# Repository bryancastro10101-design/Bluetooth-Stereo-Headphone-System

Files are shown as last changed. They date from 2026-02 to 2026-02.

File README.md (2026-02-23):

# 🎧 Bluetooth Stereo Headphone System
**EE 445L Embedded System Design Lab — Final Project | The University of Texas at Austin**

A fully functional wireless stereo audio system built from scratch using an ESP32 and TM4C123 microcontroller, featuring real-time DSP, dual TFT displays, and a custom PCB designed in KiCad.

---

## 📌 Project Overview

This project demonstrates end-to-end embedded system design — from hardware architecture and PCB layout to firmware development and digital signal processing. Audio is streamed wirelessly from a PC via Bluetooth (A2DP protocol), decoded by an ESP32, and transmitted over SPI to a TM4C123 microcontroller for processing and playback through dual speakers.

---

## 🏗️ System Architecture

```
[PC / Spotify]
     │
     │  Bluetooth A2DP
     ▼
[ESP32 DevKitC]  ──── SPI ────►  [TM4C123GH6PM]
                                       │
                          ┌────────────┴────────────┐
                          │                         │
                     [TLV5616 DAC]           [TLV5616 DAC]
                          │                         │
                    [MCP34119 OPA]           [MCP34119 OPA]
                          │                         │
                      [Speaker L]             [Speaker R]
                          
         [ST7735R LCD ×2]  ◄── SPI ── TM4C123
         [Volume Buttons ×4]
```

**Communication Protocols:**
- **Bluetooth A2DP** — Wireless audio streaming from PC to ESP32
- **SPI** — ESP32 → TM4C123 audio data transfer; TM4C123 → DACs and LCD screens
- **I2C** — ESP32 ↔ TM4C123 control/status channel

---

## ⚙️ Hardware Components

| Component | Part | Qty | Role |
|---|---|---|---|
| Microcontroller | TM4C123GH6PM | 1 | Main audio processor |
| Wireless MCU | ESP32-DevKitC-V4 | 1 | Bluetooth A2DP receiver |
| TFT Display | ST7735R | 2 | Real-time audio level UI |
| DAC | TLV5616 | 2 | Digital-to-analog conversion |
| Op-Amp | MCP34119P | 2 | Audio amplification |
| Buck Regulator | MPM3610GQV | 2 | 9V → 5V and 9V → 3.3V |
| Voltage Reference | LM4041CILPR | 1 | Stable DAC reference |

---

## 🔋 Power Budget

| Rail | Load Breakdown | Range |
|---|---|---|
| **3.3V** | TM4C123 + 2× ST7735R + ESP32 + regulators + Vref | 231 mA – 321 mA |
| **5V** | 2× MCP34119 + 2× TLV5616 | ~2.32 mA |

Both rails are supplied by MPM3610GQV switching regulators from a 9V source, chosen for their high efficiency and small footprint.

---

## 💻 Firmware Design

### ESP32 — Bluetooth Receiver
Receives audio data over Bluetooth A2DP and streams it to the TM4C123 via SPI as fast as data is available.

```c
// ESP32 pseudocode
int main() {
    while (true) {
        while (SoundDataReady) {
            SPIOut(SoundData);
        }
    }
    return 0;
}
```

### TM4C123 — Audio Processor
Acts as the SPI slave, processes incoming audio data, and distributes it to the two DAC channels and both LCD displays.

**Module structure:**
```
dac.h       → DAC_Init(), DAC_Output(uint16_t data)
slave.h     → Slave_Init(void (*handler)(uint8_t databyte))
speaker.h   → init_Speaker(), play_Sound(int soundData)
lcd.h       → init_LCD(), update_LCD(update_Params params)
```

---

## 🖥️ User Interface

- **2× ST7735R TFT displays** showing real-time audio level visualization that responds dynamically to volume
- **4 buttons** (2 per channel) for:
  - Volume control (up/down)
  - Equalization adjustment

---

## 📐 PCB Design

Designed in **KiCad** targeting **JLCPCB** manufacturing rules.

**Key design decisions:**
- Regulators placed close to the battery connector to minimize long power traces
- Speaker/Amp/DAC subcircuit routed once and mirrored for the stereo channel
- Booster pack headers spaced for TM4C123 LaunchPad compatibility
- Crystal oscillator isolated from high-speed signal traces

---

## 📊 Performance Targets

| Metric | Target |
|---|---|
| Frequency Response | 20 Hz – 20 kHz |
| SNR | ≥ 80 dB |
| Button Response Time | Measured via logic analyzer |
| Bluetooth Range | Up to ~10 m (Class 2) |

---

## 🛠️ Skills Demonstrated

- **Embedded C firmware** on ARM Cortex-M4 (TM4C123)
- **SPI/I2C protocol implementation** (master & slave)
- **Bluetooth A2DP** wireless audio protocol
- **Digital Signal Processing** — real-time audio equalization
- **PCB design** in KiCad (schematic capture, layout, DRC)
- **Analog circuit design** — DAC output stage with op-amp buffering
- **Power electronics** — switching regulator selection and layout
- **Hardware/software co-design** across two MCUs

---

## 📁 Repository Structure

```
├── firmware/
│   ├── esp32/          # Bluetooth A2DP receiver code
│   └── tm4c/           # Audio processor, DAC, LCD, SPI slave
├── hardware/
│   ├── schematic/      # KiCad schematic files
│   ├── pcb/            # KiCad PCB layout files
│   └── datasheets/     # Component datasheets
├── docs/
│   ├── system_diagram.pdf
│   ├── requirements_document.pdf
│   └── power_calculations.txt
└── README.md
```

---

## 🎓 Course Context

**EE 445L — Embedded Systems Design Lab**  
Department of Electrical and Computer Engineering  
The University of Texas at Austin

This course covers real-time embedded system design, hardware/software integration, and PCB prototyping with an emphasis on the full engineering design cycle from requirements through implementation and testing.

---

---

## 📝 Lessons Learned

The board flashed successfully with all components soldered — until the buck converters were added. Once the MPM3610GQV regulators were populated, the board could no longer be programmed via JTAG.

After consulting with other engineers, the team's leading hypothesis is **switching noise crosstalk from the buck converters into the JTAG lines**. The regulators were placed in relative proximity to the JTAG header on a 2-layer PCB, which lacks the dedicated ground and power planes of a 4-layer design. Without those inner planes acting as a Faraday shield and low-impedance return path, the high-frequency switching transients generated by the regulators likely coupled into the JTAG data lines and disrupted the debug interface.

The audio side had its own surprise as well. One of the external ADC converters was producing noticeably poor sound quality that we couldn't tune out. Rather than spin a new board, the team jumped a wire on the back of the PCB to bypass it and route the signal directly into the ESP32's onboard ADC instead — which performed considerably better. It wasn't pretty, but it worked, and the project stayed on schedule. A classic embedded engineering field fix.

**Key takeaways for future designs:**
- Move to a **4-layer stackup** (signal / ground / power / signal) to provide shielding and clean return paths — especially important when mixing switching regulators with sensitive digital interfaces
- Increase the **physical separation** between switching regulators and JTAG/SWD headers, and avoid routing debug lines near regulator switching nodes
- Add **bulk and bypass capacitance** close to the regulator output to suppress switching noise at the source
- Consider adding a **ferrite bead or LC filter** on the power rail feeding the microcontroller to further isolate debug circuitry from regulator noise

---

*Designed and implemented as part of the EE 445L final project. All schematics, firmware, and documentation produced independently.*

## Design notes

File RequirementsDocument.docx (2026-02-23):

## Project Requirements Document: Bluetooth Headphones

1) Overview
  a) Objectives: Why are we doing this project? What is the purpose?

The purpose of this project is to create a fully functional Bluetooth headphone system that demonstrates the integration of wireless audio transmission, user interface features, and sound quality. The objectives include:

Learning about Bluetooth communication protocols and implementation.

Gaining hands-on experience with embedded systems and enclosure design, particularly with the TM4C123GH6PM microcontroller and ESP32-DevKitC. Along with two of the TFT ST7735R LCD screens.

Developing skills in digital signal processing and audio amplification for improved sound output.

  b) Interactions with Existing Systems: Include this if you are connecting to another board
  c) Terminology: Define domain specific terms used in the document.

SPI - SPI is a synchronous serial communication protocol used for short-distance communication, primarily in embedded systems. It enables communication between a master device and one or more slave devices using four primary lines

I2C - I2C is a multi-master, multi-slave, synchronous serial communication protocol used for connecting low-speed devices in embedded systems. It requires only two wires

DAC - A DAC is an electronic component that converts digital signals (usually binary) into analog signals. It takes discrete values and outputs a continuous voltage or current that represents those values, enabling the representation of digital audio, video, and other signals in a form that can be understood by analog devices (like speakers or displays)

Bluetooth - Bluetooth is a wireless technology standard used for short-range communication between devices. It operates in the 2.4 GHz ISM band and allows for data exchange over distances typically up to 100 meters, depending on the Bluetooth class. Common applications include wireless audio streaming, file transfer, and connecting peripheral devices like keyboards, mice, and headphones

Voltage Regulator - A voltage regulator is an electrical device that maintains a constant output voltage level despite variations in input voltage or load conditions. It ensures that electronic components receive a stable voltage supply, which is crucial for their proper operation. Voltage regulators can be linear or switching types, with switching regulators being more efficient for higher power applications

Signal Amplitude - Signal amplitude refers to the maximum extent of a signal's variation from its rest position or average value. In the context of electrical signals, it is often measured in volts and indicates the strength or intensity of the signal. In audio applications, higher amplitude correlates to louder sounds, while in digital signals, amplitude variations can represent different binary states

Periodic Interrupts - Periodic interrupts are signals sent to a processor at regular intervals to prompt it to execute a specific piece of code or routine. This mechanism is commonly used in real-time operating systems (RTOS) and embedded systems to handle tasks that require consistent timing, such as sampling data from sensors or controlling motors. The processor can manage multiple tasks efficiently by prioritizing interrupts based on their timing

Equalization - Equalization (EQ) in Digital Signal Processing (DSP) is a technique used to adjust the balance of specific frequency components in an audio signal. It involves modifying the amplitude of different frequency bands to enhance, reduce, or modify the sound quality and tonal characteristics of audio playback

2) Functional Description
  a) Functionality: What will the system do precisely?
    i) Bluetooth Audio Streaming (connectivity)
    ii) Dual Speaker Output
    iii) User Interface with two LCD screens
    iv) Volume Control
    v) Equalization
  b) Performance: Define the measures and describe how they will be determined.

Audio Quality: Use an oscilloscope to analyze the output waveform of the speakers for frequency response of the audible hearing range: 20 Hz to 20 kHz.

SNR: Measure the output while playing a test tone at a known level and record the noise level to calculate the SNR. The target is to achieve an SNR of at least 80 dB for high-quality audio playback

Response Time: Measurements: Use a logic analyzer to measure the time from pressing a button to the corresponding action (volume change, playback toggle, or equalizer adjustment)

Equalization Effectiveness: Measurements: Evaluate the impact of the equalizer on audio output using frequency response measurements with an oscilloscope.

Determination: Compare audio signals before and after equalization to ensure intended frequency adjustments are achieved. The equalizer should demonstrate noticeable changes in specific frequency bands, allowing users to tailor the audio output to their preferences.

  c) Usability: Describe the interfaces. Be quantitative if possible

TFT Display Interface: A graphical user interface showing changing audio levels depending on the volume of the sound.

Control Buttons: 4 buttons (2 for each speaker) for volume control and equalization functionalities.

Bluetooth Connectivity (I2C)

DAC interface (SPI): Two separate DACs will be connected to process the information from the ESP32 to a corresponding speaker.

3) Deliverables
  a) Roles and Responsibilities: Who will do what? What is the purpose?
  b) Reports: Simply state the reports for Labs 7 8, and 10 will be written
  c) Outcomes: What are the deliverables? How do we know when it is done?
    i) A fully functional prototype of Bluetooth headphones
    ii) Successful pairing and audio playback
    iii) Two working LCDs that provide real-time information
    iv) Comprehensive documentation to include: schematics, code, and a final project report

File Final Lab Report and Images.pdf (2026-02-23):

Lab 10 report ECE445L

Name: __Adam Herring, Michael Mohn, Bryan Castro

EID: __ah58665, msm5332, bc36587

Semester: Fall 2024
Course: ECE445L
A) Objectives:
1. The purpose of this lab was to execute the design and implementation of the custom PCB for a Blutooth headset using both a TM4C123GH6PM and a ESP32. This project integrated two LCDs, two speakers, a 9V battery, 2 buck converters, and the many capacitors for decoupling, resistors with additional connectors for external interfacing. The overall result displayed the song title being played on both LCDs along with varying blue dots on the screen to see voltage changes in the signal being read from the ESP to the TM4C. Additionally, due to issues with the JTAG, we utilized the LaunchPad connectors to program the device. This experience provided valuable insights into the possible complexities of custom PCB design and implementation.
B) Hardware Design Deliverables:
1. N/A
C) Software Design Deliverables:
1. I have pushed my project to GitHub for grading (Yes/No):
2. Deliverable 1: System design diagram of the modules created.

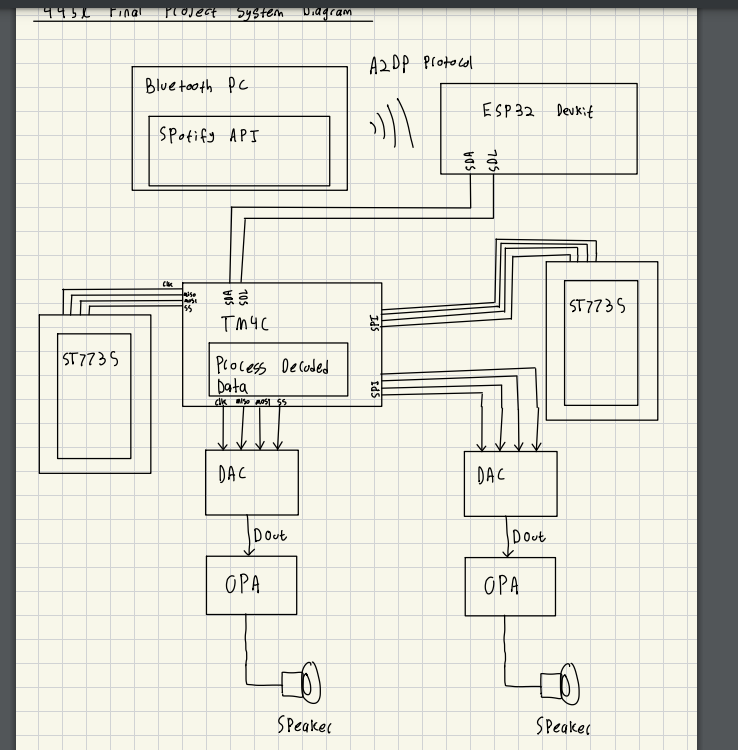
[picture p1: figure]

D) General Deliverables:
1. Deliverable 2: Software Tests
- Verification of the software modules to include Bluetooth connectivity, audio playback through both speakers, reading the ascii characters correctly for the LCDs and overall system control worked except for the external switches because of the hardware issue present with the having to use the launchpad for flashing the program through a TM4C and this launchpad covered the buttons on the PCB.
- Generalized sound quality as a test for data communication was changed from I2C to UART between the ESP32 and TM4C because of the amount of noise present was overbearing in I2C. Both synchronizations were present but there was too much ambiguity to confirm the sound output via I2C because of the noise.

2. Deliverable 3: Hardware Tests
- There were many hardware tests starting from checking if the PCB can flash a program through JTAG. When the PCB was about 90% soldered, aside from the buck converters, we were able to flash the board with no problem. However, after soldering the buck converters, we could not flash any code onto the TM4C of the PCB. After confirming proper voltage values of 3.3V and 1.2V for LDO with the converters soldered and the reset functionality, we deduced the issue of not being able to flash the board to cross talk between the JTAG ports and one of the buck converters that was close to the pins.
- We ensured all 4 test points soldered onto the PCB were functioning properly, with the main focus on ensuring the buck converters change the 9V from the external batter to be changed to 3.3V and 5V. The other two test points were on the out signal of the DACs and before the op-amps needed more testing as we encountered noise in the overall sound output.
3. Deliverable 4: Power consumption

Power consumption for KICAD Lab 7 and 10

Current Drawn from IC (Look at worse case scenario)

(1) TM4C123: ~30–40 mA
(2) ST7735R: ~40 mA
(2) MCP34119P: ~120 µA (per amplifier)
(2) TLV5616: ~1 mA per amp
(1) ESP32 - DEVKITC - V4: ~160–240 mA
(1) MPM3610GQV (From 9V to 5V): ~200 µA
(1) MPM3610GQV (From 9V to 3.3V): ~200 µA
(1) LM4041CILPR: ~60–100 µA

Total Load Currents

For 5V: (~120 µA) +(~120 µA) + (~1 mA) + (~1 mA) + (~160–240 mA) = 160 to 240mA

For 3.3V: (~30–40 mA) + (~40 mA) + (~40 mA) + (~200 µA) + (~200 µA) + (~60–100 µA) = 110.46 mA to 120.5 mA,

4. Deliverable 5 (10pt EC): Characterization of the system
E) Analysis and Discussion Questions:
1. N/A

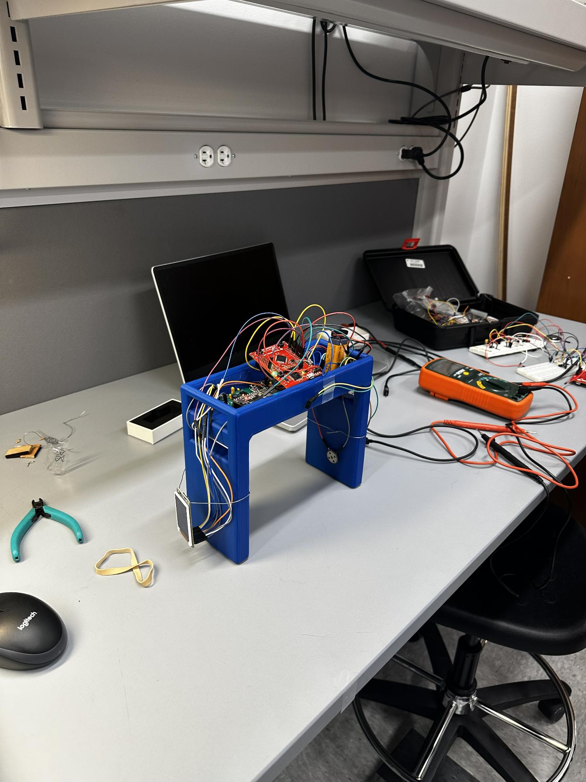
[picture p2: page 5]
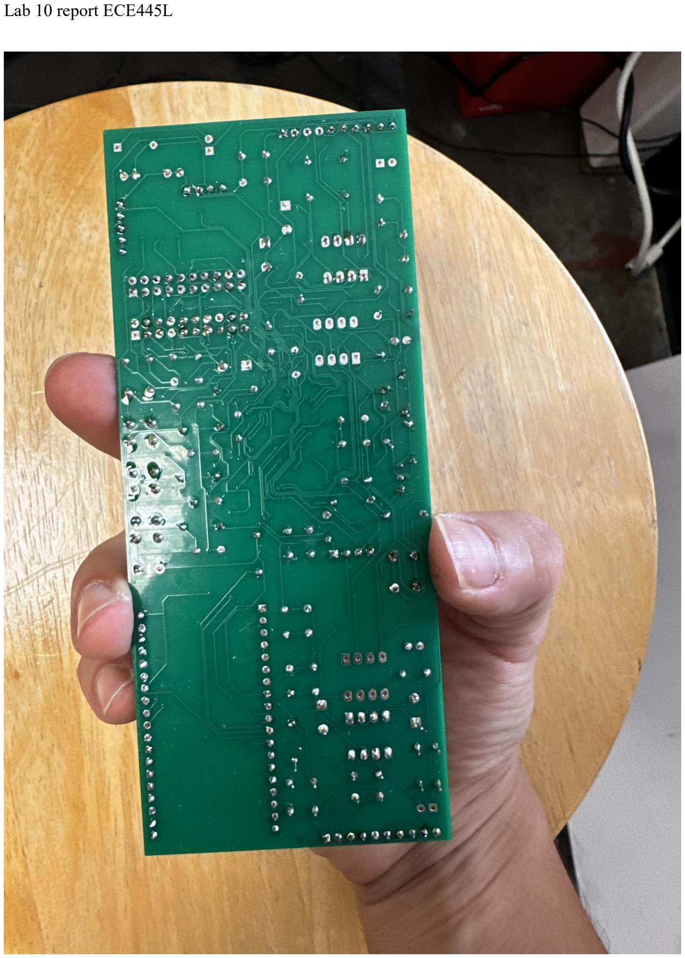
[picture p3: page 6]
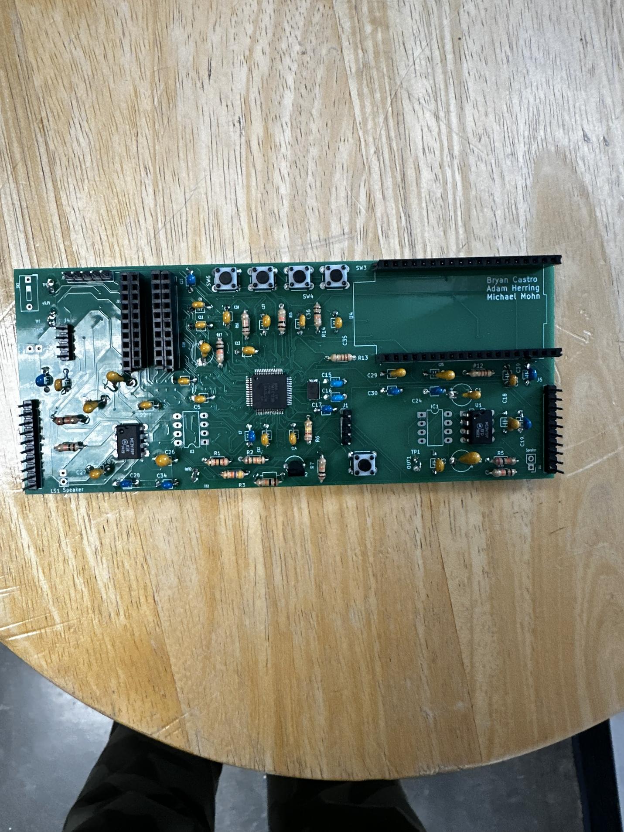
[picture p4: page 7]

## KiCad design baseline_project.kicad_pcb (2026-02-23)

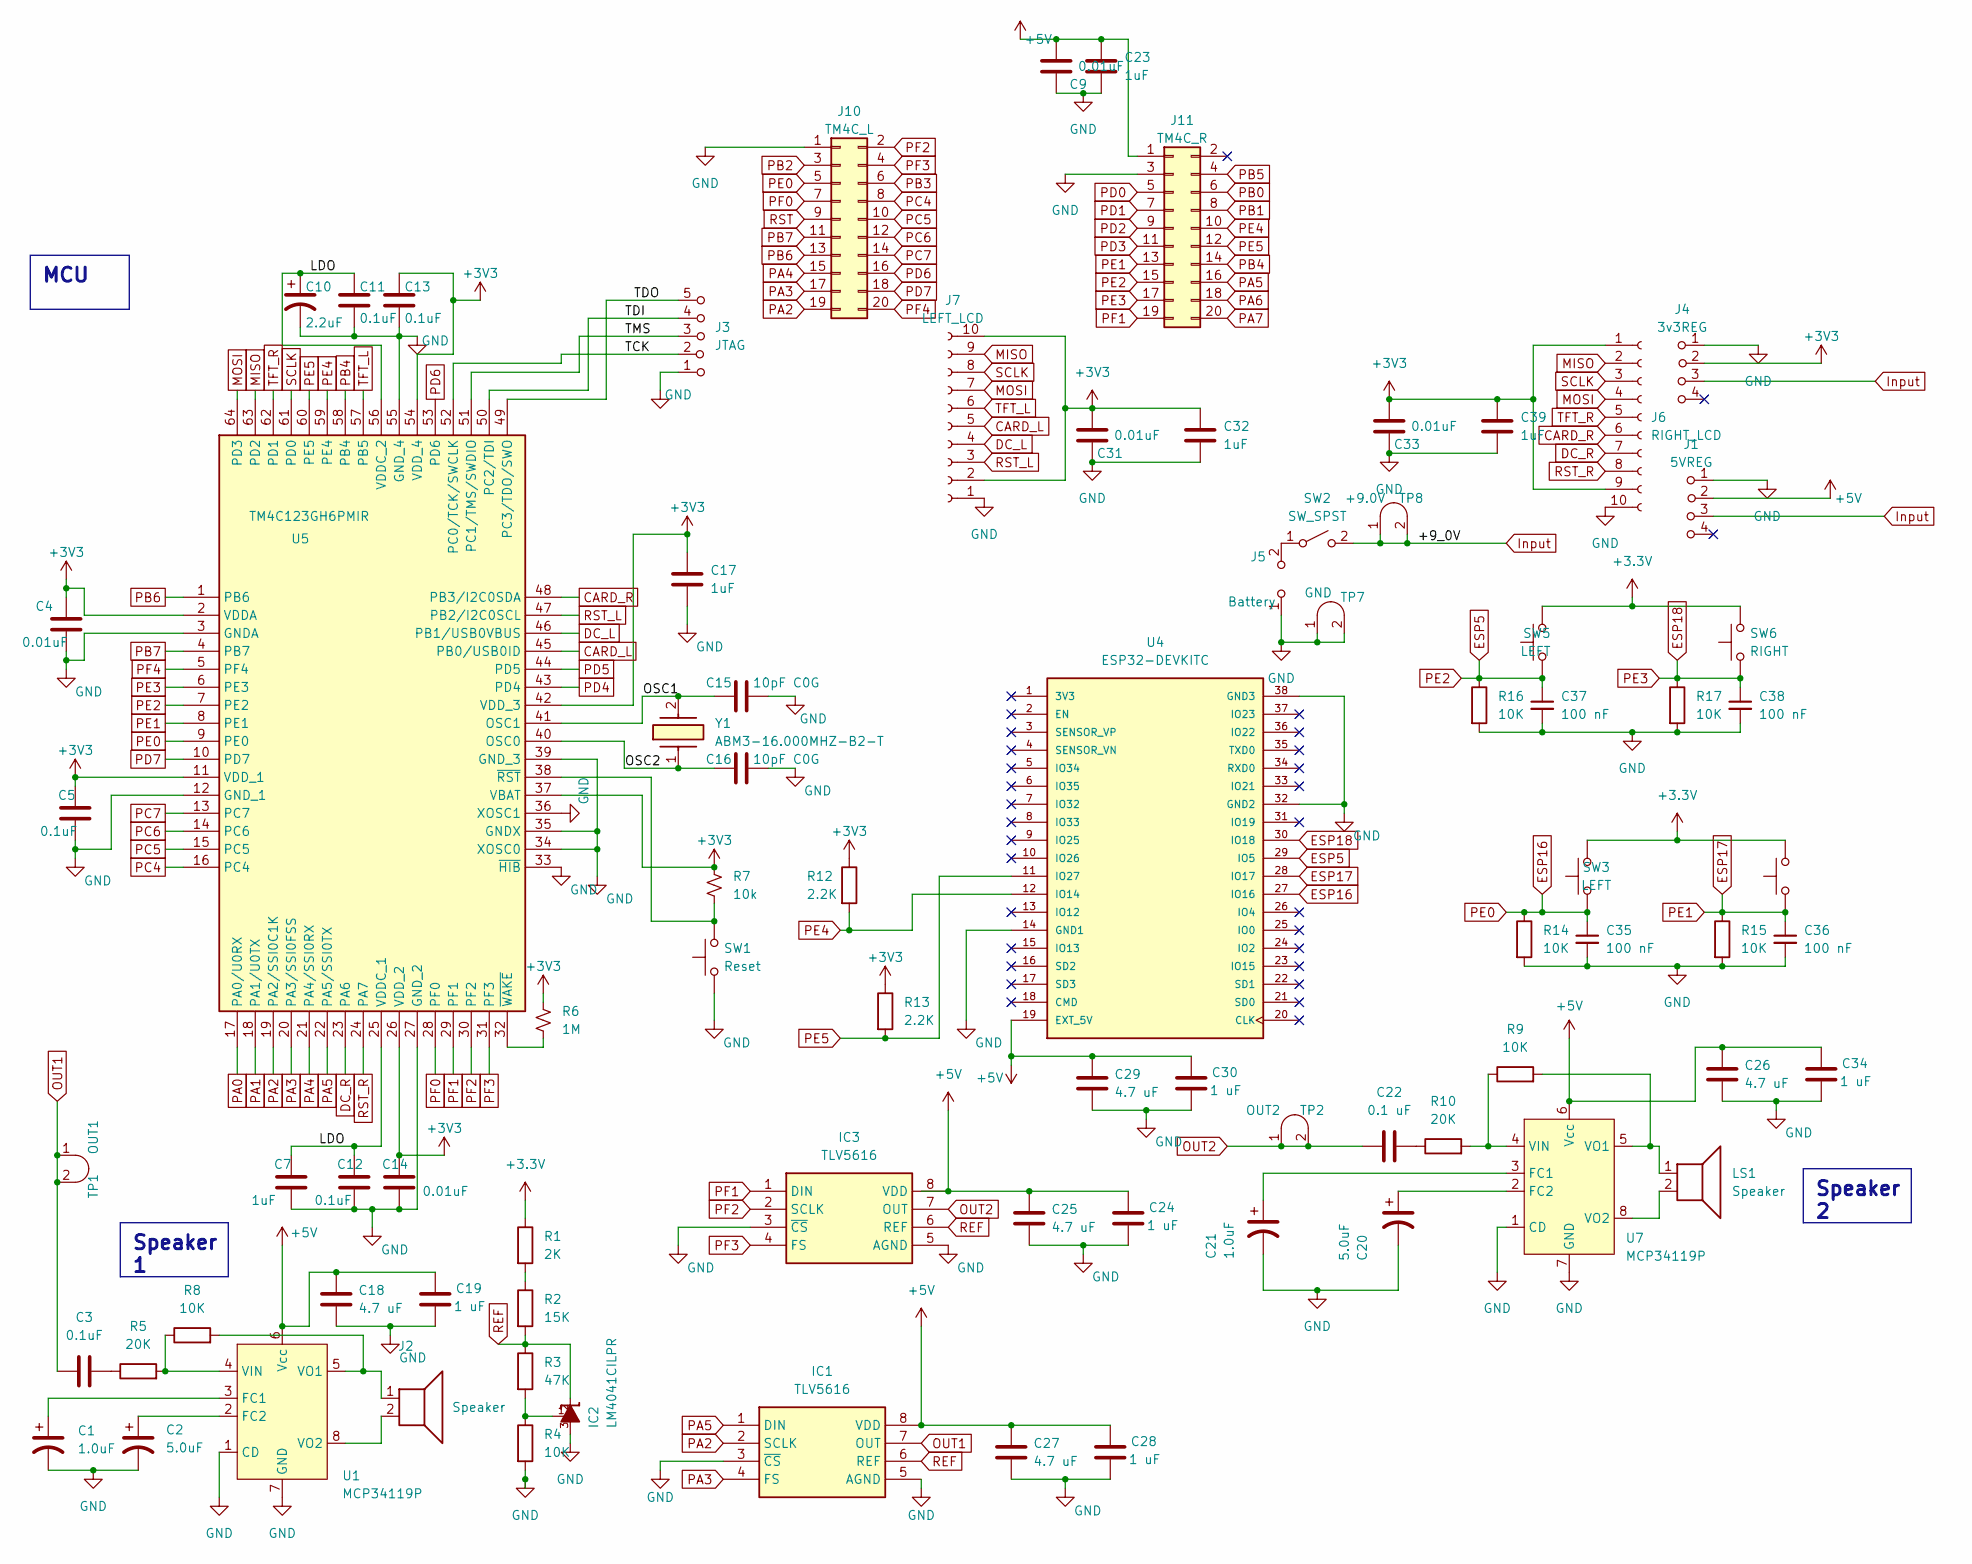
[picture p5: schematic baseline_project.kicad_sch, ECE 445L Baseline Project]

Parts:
C1, C21: 1.0uF; CP_Radial_Tantal200mil
C2, C20: 5.0uF; CP_Radial_Tantal200mil
C3, C5, C11, C12, C13: 0.1uF; C_Axial_200mil
C4, C9, C14, C31, C33: 0.01uF; C_Axial_200mil
C7, C17, C23, C32, C39: 1uF; C_Axial_200mil
C10: 2.2uF; CP_Radial_Tantal200mil
C15, C16: 10pF C0G; C_Axial_200mil
C18, C25, C26, C27, C29: 4.7 uF; C_Axial_200mil
C19, C24, C28, C30, C34: 1 uF; C_Axial_200mil
C22: 0.1 uF; C_Axial_200mil
C35, C36, C37, C38: 100 nF; C_Axial_200mil
IC1, IC3: TLV5616; DIP-8_W7.62mm_LongPads
IC2: LM4041CILPR; ti_LM4041CILPR
J1: 5VREG; PinHeader_1x04_P2.54mm_Vertical
J2: Speaker; PinHeader_1x02_P2.54mm_Vertical
J3: JTAG; PinHeader_1x05_P2.54mm_Vertical
J4: 3v3REG; PinHeader_1x04_P2.54mm_Vertical
J5: Battery; PinHeader_1x02_P2.54mm_Vertical
J6: RIGHT_LCD; PinHeader_1x10_P2.54mm_Vertical
J7: LEFT_LCD; PinHeader_1x10_P2.54mm_Vertical
J10: TM4C_L; PinSocket_2x10_P2.54mm_Vertical
J11: TM4C_R; PinSocket_2x10_P2.54mm_Vertical
LS1: Speaker; PinHeader_1x02_P2.54mm_Vertical
R1: 2K; R_Axial_DIN0204_L3.6mm_D1.6mm_P7.62mm_Horizontal
R2: 15K; R_Axial_DIN0204_L3.6mm_D1.6mm_P7.62mm_Horizontal
R3: 47K; R_Axial_DIN0204_L3.6mm_D1.6mm_P7.62mm_Horizontal
R4, R8, R9, R14, R15, R16, R17: 10K; R_Axial_DIN0204_L3.6mm_D1.6mm_P7.62mm_Horizontal
R5, R10: 20K; R_Axial_DIN0204_L3.6mm_D1.6mm_P7.62mm_Horizontal
R6: 1M; R_Axial_DIN0204_L3.6mm_D1.6mm_P7.62mm_Horizontal
R7: 10k; R_Axial_DIN0204_L3.6mm_D1.6mm_P7.62mm_Horizontal
R12, R13: 2.2K; R_Axial_DIN0204_L3.6mm_D1.6mm_P7.62mm_Horizontal
SW1: Reset; SW_PUSH_6mm
SW2: SW_SPST; SW_DIP_SPSTx01_Slide_9.78x4.72mm_W7.62mm_P2.54mm
SW3, SW5: LEFT; SW_PUSH_6mm
SW4, SW6: RIGHT; SW_PUSH_6mm
TP1: OUT1; Testpoint_1x02_P2.54mm
TP2: OUT2; Testpoint_1x02_P2.54mm
TP7: GND; Testpoint_1x02_P2.54mm
TP8: +9.0V; Testpoint_1x02_P2.54mm
U1, U7: MCP34119P; DIP-8_W7.62mm_LongPads
U4: ESP32-DEVKITC; MODULE_ESP32-DEVKITC; PARTREV N/A
U5: TM4C123GH6PMIR; QFP50P1200X1200X160-64N; Mouser Part Number 595-TM4C123GH6PMIR
Y1: ABM3-16.000MHZ-B2-T; ABM3; Mouser Part Number 815-ABM3-16-B2-T

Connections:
+3.3V: R1.1, SW3.2, SW4.2, SW5.2, SW6.2
+3V3: C4.1, C5.1, C13.1, C14.1, C17.1, C31.2, C32.1, C33.2, C39.1, J4.2 (B), J6.1, J6.9, J7.2, J7.10, R6.1, R7.1, R12.1, R13.1, U5.2 (VDDA), U5.11 (VDD_1), U5.26 (VDD_2), U5.37 (VBAT), U5.42 (VDD_3), U5.54 (VDD_4); also elsewhere on the board
+5V: C9.2, C18.2, C19.2, C23.1, C24.2, C25.2, C26.2, C27.2, C28.2, C29.2, C30.2, C34.2, IC1.8 (VDD), IC3.8 (VDD), J1.2 (B), J11.1, U1.6 (Vcc), U4.19 (EXT_5V), U7.6 (Vcc); also elsewhere on the board
/LDO: C7.1, C10.1, C11.1, C12.1, U5.25 (VDDC_1), U5.56 (VDDC_2)
/OSC1: C15.1, U5.41 (OSC1), Y1.2
/OSC2: C16.1, U5.40 (OSC0), Y1.1
/TCK: J3.2 (B), U5.52 (PC0/TCK/SWCLK); also elsewhere on the board
/TDI: J3.4 (C), U5.50 (PC2/TDI); also elsewhere on the board
/TDO: J3.5 (C), U5.49 (PC3/TDO/SWO); also elsewhere on the board
/TMS: J3.3 (C), U5.51 (PC1/TMS/SWDIO); also elsewhere on the board
CARD_L: J7.5, U5.45 (PB0/USB0ID); also elsewhere on the board
CARD_R: J6.6, U5.48 (PB3/I2C0SDA); also elsewhere on the board
DC_L: J7.4, U5.46 (PB1/USB0VBUS); also elsewhere on the board
DC_R: J6.7, U5.23 (PA6); also elsewhere on the board
ESP5: C37.1, J11.15, R16.1, SW5.1, U4.29 (IO5), U5.7 (PE2); also elsewhere on the board
ESP16: C35.1, J10.5, R14.1, SW3.1, U4.27 (IO16), U5.9 (PE0); also elsewhere on the board
ESP17: C36.1, J11.13, R15.1, SW4.1, U4.28 (IO17), U5.8 (PE1); also elsewhere on the board
ESP18: C38.1, J11.17, R17.1, SW6.1, U4.30 (IO18), U5.6 (PE3); also elsewhere on the board
GND: C1.2, C2.2, C4.2, C5.2, C7.2, C9.1, C10.2, C11.2, C12.2, C13.2, C14.2, C15.2, C16.2, C17.2, C18.1, C19.1, C20.2, C21.2, C23.2, C24.1, C25.1, C26.1, C27.1, C28.1, C29.1, C30.1, C31.1, C32.2, C33.1, C34.1, C35.2, C36.2, C37.2, C38.2, C39.2, IC1.3 (~CS), IC1.5 (AGND), IC2.3, IC3.3 (~CS), IC3.5 (AGND), J1.1 (A), J3.1 (A), J4.1 (A), J5.1 (A), J6.10, J7.1, J10.1, J11.3, R4.2, R14.2, R15.2, R16.2, R17.2, SW1.1, TP7.1 (A), TP7.2 (B), U1.1 (CD), U1.7 (GND), U4.14 (GND1), U4.32 (GND2), U4.38 (GND3), U5.3 (GNDA), U5.12 (GND_1), U5.27 (GND_2), U5.33 (~HIB), U5.34 (XOSC0), U5.35 (GNDX), U5.36 (XOSC1), U5.39 (GND_3), U5.55 (GND_4), U7.1 (CD), U7.7 (GND); also elsewhere on the board
Input: J1.3 (C), J4.3 (C), SW2.2 (B), TP8.1 (A), TP8.2 (B)
MISO: J6.2, J7.9, U5.63 (PD2); also elsewhere on the board
MOSI: J6.4, J7.7, U5.64 (PD3); also elsewhere on the board
unnamed: C3.2, R5.1
unnamed: C22.2, R10.1
unnamed: IC2.1, R3.2, R4.1
unnamed: J5.2 (B), SW2.1 (A)
unnamed: R1.2, R2.1
unnamed: C1.1, U1.3 (FC1)
unnamed: C2.1, U1.2 (FC2)
unnamed: R5.2, R8.1, U1.4 (VIN)
unnamed: J2.1, R8.2, U1.5 (VO1)
unnamed: J2.2, U1.8 (VO2)
unnamed: R7.2, SW1.2, U5.38 (~RST)
unnamed: R6.2, U5.32 (~WAKE)
unnamed: C21.1, U7.3 (FC1)
unnamed: C20.1, U7.2 (FC2)
unnamed: R9.1, R10.2, U7.4 (VIN)
unnamed: LS1.1, R9.2, U7.5 (VO1)
unnamed: LS1.2, U7.8 (VO2)
OUT1: C3.1, IC1.7 (OUT), TP1.1 (A), TP1.2 (B)
OUT2: C22.1, IC3.7 (OUT), TP2.1 (A), TP2.2 (B)
PA0: U5.17 (PA0/U0RX)
PA1: U5.18 (PA1/U0TX)
PA2: IC1.2 (SCLK), J10.19, U5.19 (PA2/SSI0C1K); also elsewhere on the board
PA3: IC1.4 (FS), J10.17, U5.20 (PA3/SSI0FSS); also elsewhere on the board
PA4: J10.15, U5.21 (PA4/SSI0RX); also elsewhere on the board
PA5: IC1.1 (DIN), J11.16, U5.22 (PA5/SSI0TX); also elsewhere on the board
PB4: J11.14, U5.58 (PB4); also elsewhere on the board
PB6: J10.13, U5.1 (PB6); also elsewhere on the board
PB7: J10.11, U5.4 (PB7); also elsewhere on the board
PC4: J10.8, U5.16 (PC4); also elsewhere on the board
PC5: J10.10, U5.15 (PC5); also elsewhere on the board
PC6: J10.12, U5.14 (PC6); also elsewhere on the board
PC7: J10.14, U5.13 (PC7); also elsewhere on the board
PD4: U5.43 (PD4)
PD5: U5.44 (PD5)
PD6: J10.16, U5.53 (PD6); also elsewhere on the board
PD7: J10.18, U5.10 (PD7); also elsewhere on the board
PE4: J11.10, R12.2, U4.12 (IO14), U5.59 (PE4); also elsewhere on the board
PE5: J11.12, R13.2, U4.11 (IO27), U5.60 (PE5); also elsewhere on the board
PF0: J10.7, U5.28 (PF0); also elsewhere on the board
PF1: IC3.1 (DIN), J11.19, U5.29 (PF1); also elsewhere on the board
PF2: IC3.2 (SCLK), J10.2, U5.30 (PF2); also elsewhere on the board
PF3: IC3.4 (FS), J10.4, U5.31 (PF3); also elsewhere on the board
PF4: J10.20, U5.5 (PF4); also elsewhere on the board
REF: IC1.6 (REF), IC2.2, IC3.6 (REF), R2.2, R3.1
RST_L: J7.3, U5.47 (PB2/I2C0SCL); also elsewhere on the board
RST_R: J6.8, U5.24 (PA7); also elsewhere on the board
SCLK: J6.3, J7.8, U5.61 (PD0); also elsewhere on the board
TFT_L: J7.6, U5.57 (PB5); also elsewhere on the board
TFT_R: J6.5, U5.62 (PD1); also elsewhere on the board

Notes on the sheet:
MCU
Speaker 2
Speaker 1

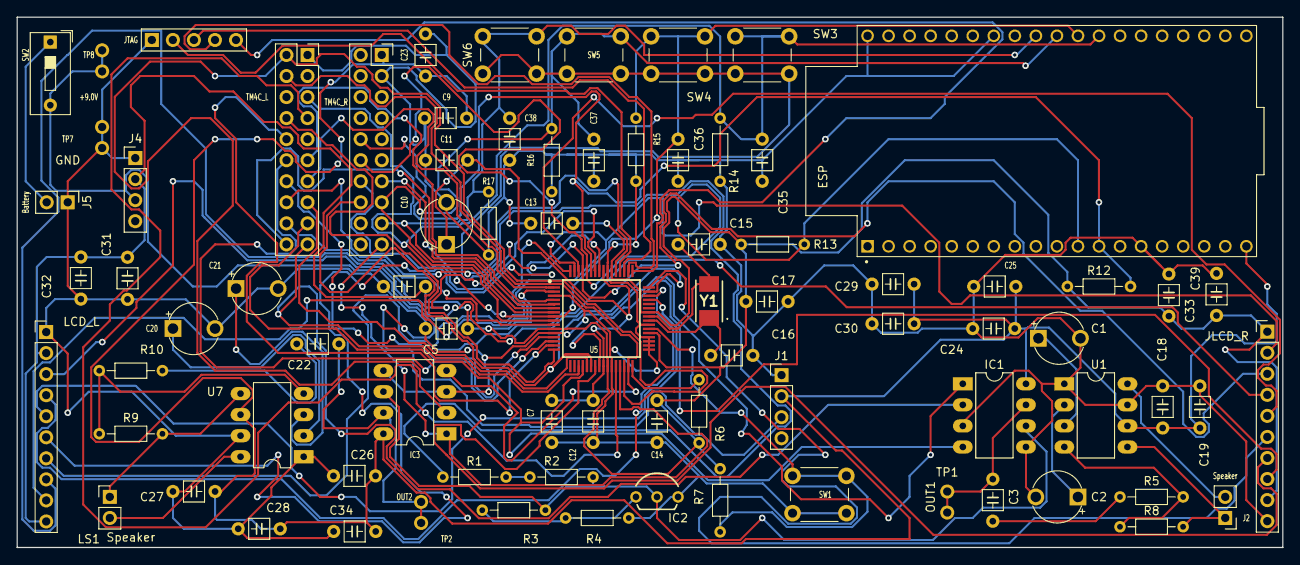
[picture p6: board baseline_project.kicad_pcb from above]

Board: 2 copper layers, 152.8 x 64.0 mm, 81 parts (0 on the bottom side), 67 nets.

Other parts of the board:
ESP: ESP32-DEVKITC; MODULE_ESP32-DEVKITC
JLCD_R: RIGHT_LCD; PinHeader_1x10_P2.54mm_Vertical
JTAG: JTAG; PinHeader_1x05_P2.54mm_Vertical
LCD_L: LEFT_LCD; PinHeader_1x10_P2.54mm_Vertical
TM4C_L: TM4C_L; PinSocket_2x10_P2.54mm_Vertical
TM4C_R: TM4C_R; PinSocket_2x10_P2.54mm_Vertical

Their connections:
+3V3: JLCD_R.1, JLCD_R.9, LCD_L.2, LCD_L.10; also elsewhere on the board
+5V: ESP.19 (EXT_5V), TM4C_R.1; also elsewhere on the board
/TCK: JTAG.2 (B); also elsewhere on the board
/TDI: JTAG.4 (C); also elsewhere on the board
/TDO: JTAG.5 (C); also elsewhere on the board
/TMS: JTAG.3 (C); also elsewhere on the board
CARD_L: LCD_L.5; also elsewhere on the board
CARD_R: JLCD_R.6; also elsewhere on the board
DC_L: LCD_L.4; also elsewhere on the board
DC_R: JLCD_R.7; also elsewhere on the board
ESP5: ESP.29 (IO5), TM4C_R.15; also elsewhere on the board
ESP16: ESP.27 (IO16), TM4C_L.5; also elsewhere on the board
ESP17: ESP.28 (IO17), TM4C_R.13; also elsewhere on the board
ESP18: ESP.30 (IO18), TM4C_R.17; also elsewhere on the board
GND: ESP.14 (GND1), ESP.32 (GND2), ESP.38 (GND3), JLCD_R.10, JTAG.1 (A), LCD_L.1, TM4C_L.1, TM4C_R.3; also elsewhere on the board
MISO: JLCD_R.2, LCD_L.9; also elsewhere on the board
MOSI: JLCD_R.4, LCD_L.7; also elsewhere on the board
PA2: TM4C_L.19; also elsewhere on the board
PA3: TM4C_L.17; also elsewhere on the board
PA4: TM4C_L.15; also elsewhere on the board
PA5: TM4C_R.16; also elsewhere on the board
PB4: TM4C_R.14; also elsewhere on the board
PB6: TM4C_L.13; also elsewhere on the board
PB7: TM4C_L.11; also elsewhere on the board
PC4: TM4C_L.8; also elsewhere on the board
PC5: TM4C_L.10; also elsewhere on the board
PC6: TM4C_L.12; also elsewhere on the board
PC7: TM4C_L.14; also elsewhere on the board
PD6: TM4C_L.16; also elsewhere on the board
PD7: TM4C_L.18; also elsewhere on the board
PE4: ESP.12 (IO14), TM4C_R.10; also elsewhere on the board
PE5: ESP.11 (IO27), TM4C_R.12; also elsewhere on the board
PF0: TM4C_L.7; also elsewhere on the board
PF1: TM4C_R.19; also elsewhere on the board
PF2: TM4C_L.2; also elsewhere on the board
PF3: TM4C_L.4; also elsewhere on the board
PF4: TM4C_L.20; also elsewhere on the board
RST_L: LCD_L.3; also elsewhere on the board
RST_R: JLCD_R.8; also elsewhere on the board
SCLK: JLCD_R.3, LCD_L.8; also elsewhere on the board
TFT_L: LCD_L.6; also elsewhere on the board
TFT_R: JLCD_R.5; also elsewhere on the board
